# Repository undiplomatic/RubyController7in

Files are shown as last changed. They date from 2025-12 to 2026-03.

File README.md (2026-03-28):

# Open Source 7" FPV Controller with Display for RubyFPV

>[!NOTE]
>This is not a production ready controller, it may contain design faults. I am **not an engineer** and cannot vouch for its safety.
>Ergonomics are still very basic. Uses a low cost screen, with plans to update for a high brightness outdoor screen once testing completes. HDMI would also be useful for use with goggles, but not yet sure how to implement that.

>[!TIP]
>Although designed for RubyFPV, no reason it cant be used for other systems such as OpenHD so long as they support a Raspberry Pi. OpenIPC doesn't support control link at this time.

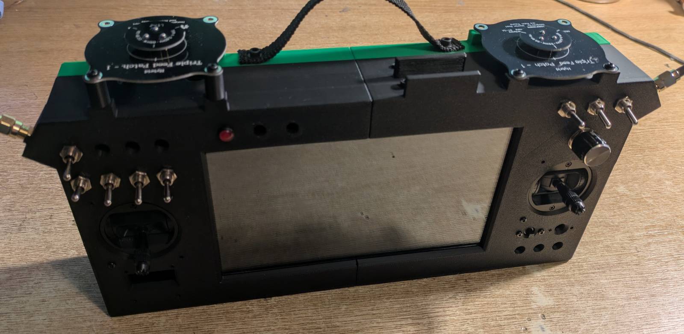
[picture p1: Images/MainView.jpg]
Main View


## Why RubyFPV
Around 2025 RubyFPV matured into a stable digital FPV and link system. Users report it operates flawlessly without stutters or break-ups. In my home testing, Ruby achieves approximately 75% of the range of DJI O4. As of early 2026, RubyFPV is working on integrating specialist FPV modules which will further improve the link. These upcoming modules will provide an even more stable link, more range, and lower latency. They will support multiple frequency bands, a first for digital FPV, including traditional 5.8GHz and low-frequency bands for long range.

Open source FPV eliminates vendor lock-in, privacy concerns, and lack of feedback associated with closed systems. For example, DJI has been shown to have back doors in their hardware, forcing changes without an update in the UK. DJI also require activation, restrict certain features for non-DJI drones (eg head tracking), and leave certain features out of date (eg SBUS). Because RubyFPV is open, it can be fully customised for industrial, academic, or developer applications. It also handles video, telemetry, and control signals over a single link and supports advanced features like signal relaying and antenna trackers.

## Why This Controller
This 3D-printed controller includes features missing on commercial systems, such as a six-position switch specifically for Ardupilot flight modes, along with a high number of assignable switches. Because RubyFPV supports multiple concurrent links across different frequencies, this controller has the internal space to house multiple transceiver modules simultaneously.

## Features
| Feature | Description | |
| :--- | :--- | :--- |
| 7 inch screen | Good size screen, reasonably priced | ✅ |
| Combined Screen and Controller | No need for a separate control link such as ELRS | ✅ |
| Raspberry Pi / Radxa Rock based |  | ✅ |
| Open source joystick controller | Uses highly configurable FreeJoy HID controller, allowing large number of switches and pots | ✅ |
| Radiomaster AG1 Hall Sensor Gimbals | Beware: the hall sensor wires on Radiomaster are mis-coloured, remove wires and check polarity printed on sensors. Available in CNC or low cost plastic. | ✅ |
| Built in open source patch antennas | Low profile, low cost, perfect radiation beam for long range | ✅ |
| Diversity omni antennas | V shaped antennas to reduce blind spots | ✅ |
| RTL EU2 Wifi chips with heat sinks | Transceivers mount on integrated heat sinks | ✅ |
| Active cooling | Two large fans | ✅ |
| Rotary switch | Rotary switches support large number of positions, suitable for flight modes on Ardupilot etc | ✅ |
| Power switch guard | Knock guard protects against accidental on/off | ✅ |
| Mini nav stick | Used to navigate through RubyFPV menus. Spare nav stick for screen control. | ✅ |
| LCD Screen | Used for aux display on RubyFPV | ✅ |
| External USB port | Used to update firmware | ✅ |
| High brightness outdoor screen | 2000 nit screen coming later | ⏳ |
| Ergonomics | Improved ergonomics coming later | ⏳ |

>[!NOTE]
>Files created in FreeCAD for easy updating.
>STL files in multiple parts to fit typical 3D printers.

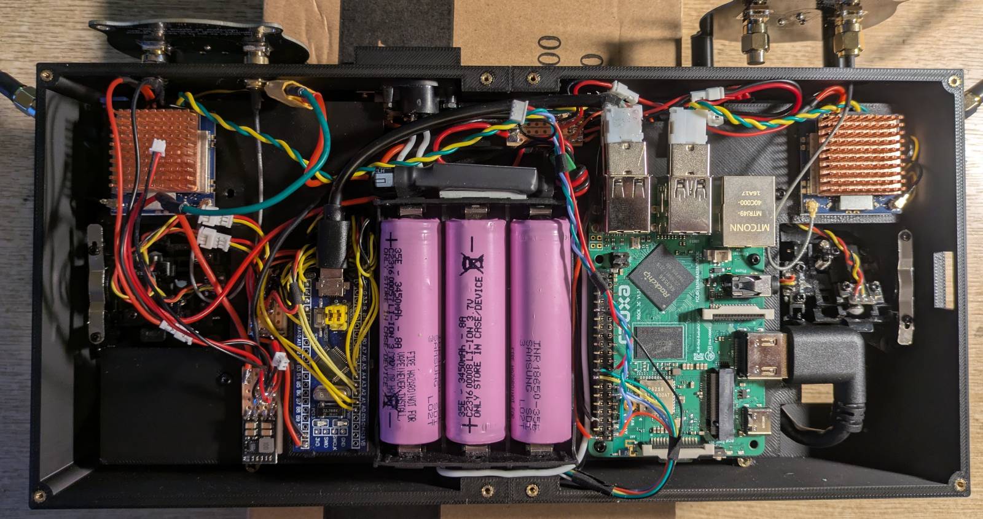
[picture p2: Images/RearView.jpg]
Rear View

Wiring looks complex: it's not, the switches and gimbal wiring create that illusion.

>[!NOTE]
>The RTL chips get hot. Heat sinks are glued into the board, and the RTL modules are attached to the sinks using thermal adhesive tape.
>The board you see creates two levels inside the controller. The bottom level houses the screen, wiring and gimbals. The top level houses the Radxa/Raspberry, batteries, HID joystick controller, and RTL modules.

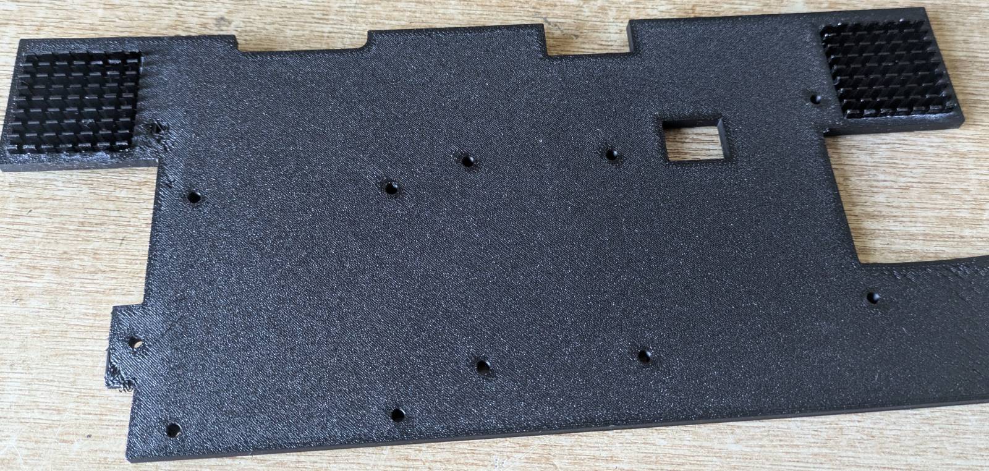
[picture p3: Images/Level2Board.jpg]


## Radiomaster AG01 Gimbal Wiring Warning

I found that the gimbals do not follow red/black wiring convention, with the red wire connected to the -ve and black wire to the +ve. The hall sensors have + and - markings on the PCB which appear correct.

## Part List

| | Part | Description |
| :--- | :--- | :--- |
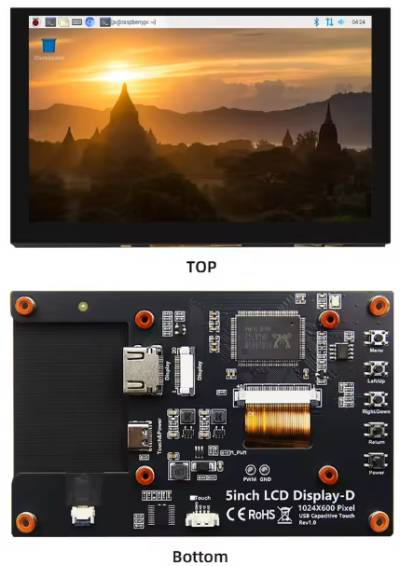
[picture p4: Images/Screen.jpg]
|  | Screen | Generic Raspberry Pi HDMI display, 7 inch. Find this **exact** screen to ensure a fit. |
| | SoC Computer | Raspberry Pi or Radxa Rock |
| | Gimbals | Radiomaster AG01 gimbals |
| | RTL WiFi modules | Two RTL8812EU-CG Long Distance drone modules act as transceivers |
| | Blue Pill STM32 | Low cost device that is flashed with FreeJoy. Solder all the hall sensors, switches, and pots to it. |
| | BEC or Voltage Regulators | 5.0v. Beware, many are 5.2v which isn't ideal, though still in tolerance for some 5v devices. But check voltage is no higher! I run TWO regulators, one powers the SoC and one RTL WiFi module. The other powers the fans and second RTL module. This is recommended so that a short in the fans doesn't cause outage. |
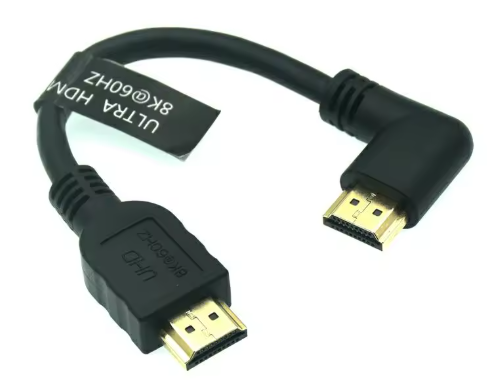
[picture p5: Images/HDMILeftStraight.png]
HMDI Cable Left-Straight 15cm
|  | HDMI Cable | 15cm left plug and straight plug other end |
| | Battery holder | Three 18650 cell holder |
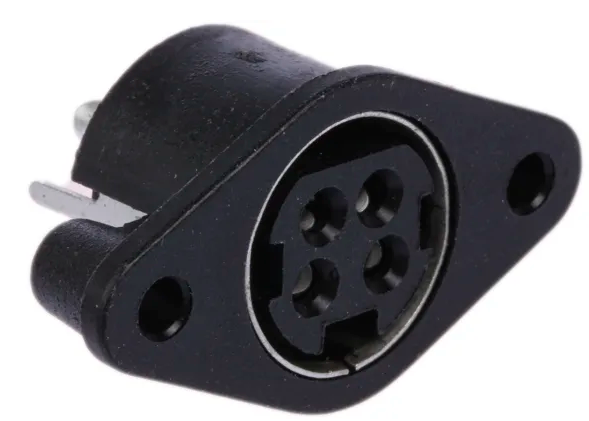
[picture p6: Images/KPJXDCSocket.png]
Kycon socket
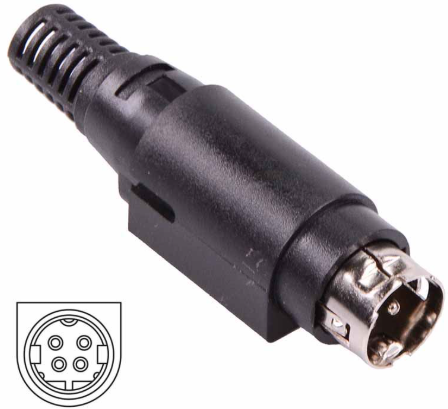
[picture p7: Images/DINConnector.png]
DIN Connector
|  | DC Socket | Kycon KPJX Straight DC Socket, part KPJX-PM-4S. These are not cheap, but are the only 4 pin DC plugs I can find. Male end is more common, often called a DIN plug even though not DIN compatible. Real DIN plugs have thinner pins and not suitable for DC charging. |
| | Patch Antennas x2 | Triple feed patch antenna, low cost, open source design. You also need 50 ohm SMA terminals for them to work properly. |
| | Omni Antennas x2 | SMA Antennas |
| | Fans x2 | 4010 5v fans. Wire to second voltage regulator for safety. |
| | Slide Switch | 6amp switch for main power, 27.5mm hole spacing +/- 1mm. Typically marked "6a 125v/3a 240v". Product title often states 3 amps, but specs show 6 amp at lower voltages. |
| | Toggle switches | MTS series generic toggle switches |
| | Rotary switch | SR16 |
| | Heat sinks | 30x30mm alu |
| | SMA U.FL Connectors | Two male SMAs for the omni antennas and two females for the patch antennas. The other end should be IPEX or U.FL. I believe they are the same, one being a brand name. |
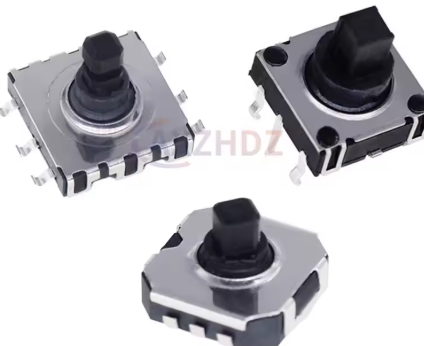
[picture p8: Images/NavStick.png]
Mini Nav Switch
| | Mini Nav switch | Five Way Switch SMD DIP 6Pin Multi Directional Mobile Navigation Switch Touch Reset Key 7.5x7.5 |
| | LCD Display | Optional 0.96" I2C OLED Display Module |
| | LEDs | 6mm hole, 5v. I suggest using 12/24v LED for the power LED to keep brightness low. |
| | M2 brass inserts | |
| | Current/voltage sensor | INA219 I2C sensor. I found only the Ada Fruit was detected by my Radxa. Raspberry Pi should work with generic sensors. |
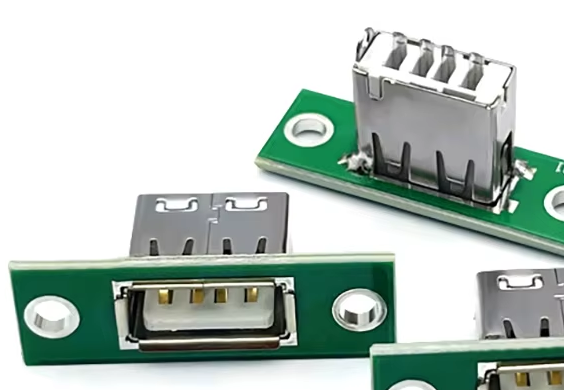
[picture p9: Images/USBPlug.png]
USB Plug
|  | USB plugs | Self solder type, male and one female |
| | Silicone wire | 30 AWG |
| | 1.25mm Connectors | Small, JST like connectors such as Molex PicoBlade or MX 1.25 |
| | 18650 Li-Ion Cells | |
| | 2mm Steel Wire | Used as dowels to join the two halves of the controller case |

... and other misc items: thermal adhesive tape, resistors for rotary switch and three position switches, and probably more things I've forgotten about.

## Charging Lead

The controller uses a 4-pin DC plug as a balance lead, with pins wired to each junction of the three battery cells. Due to space constraints, there is no dedicated main power socket. Since most chargers do not support charging  via the balance lead alone, you can use a breakout lead (an XT30 plug connected to the two outer junctions). While this is electrically the same as a standard charging setup, the power is "tapped" from  balance wires, therefore, you must charge at a low current to prevent issues.

```
DC PLUG PIN:(1)         (2)         (3)         (4)
             |           |           |           |
             +--[Cell1]--+--[Cell2]--+--[Cell3]--+
             |  (3.7V)      (7.4V)      (11.1V)  |
             |                                   |
 XT30:  NEG (-)                             POS (+)
```

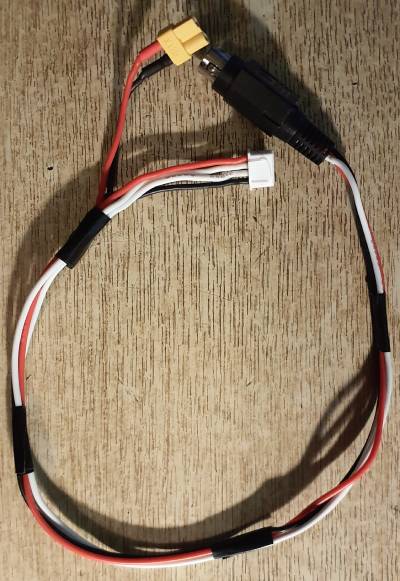
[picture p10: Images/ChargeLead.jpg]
Charge Lead


## USB and hall sensor wiring

* __Tightly__ twist the USB data wires and keep them as short as possible
* __Lightly__ twist the hall sensor wires and keep them as short as possible
* WiFi transceivers should take power direct from the voltage regulators. USB power is insufficient at high outputs.

## Three position switches

* These should be wired to an analogue terminal on the Joystick Blue Pill STM32 controller.
* Two 5k resistors from centre terminal to outer terminals.
* Power and Ground from the joystick controller to the switch outer terminals.
* Centre switch terminal to analogue pin

```
SWITCH PIN: (GND)   (Analogue Pin)    (3.3v)
                |          |          | 
                +---[R1]---+---[R1]---+
                [#### SWITCH BODY ####]

```

## Rotary switch

* Solder small resistors between the terminals create a "voltage ladder" (Google "rotary switch voltage ladder").
* The total resistance should sum to ~10 kOhms
* Wire to an analogue input on the Joystick HID Blue Pill STM32 controller

Ardupilot flight mode channel is a pain as the switch boundaries are not configurable, so each notch on the switch may not move the flightmode by one setting. This is because Ardu doesn't use the first and last 10% of the band. Thankfully, FreeJoy *axes curves* can fix this. The image shows how to configure the curve for a six position switch: notice that the line starts at -80% and ends at 80%, which compresses the band into what Ardu expects.

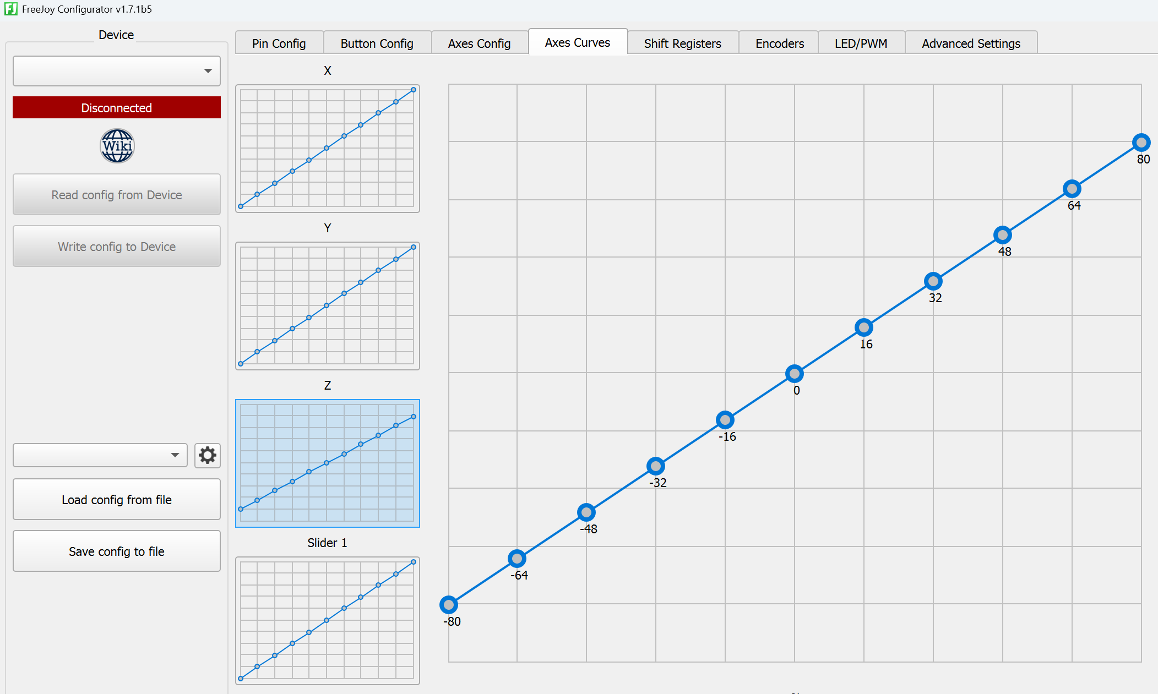
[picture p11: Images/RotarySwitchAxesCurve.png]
Axes curve to fix switch boundaries in Ardupilot


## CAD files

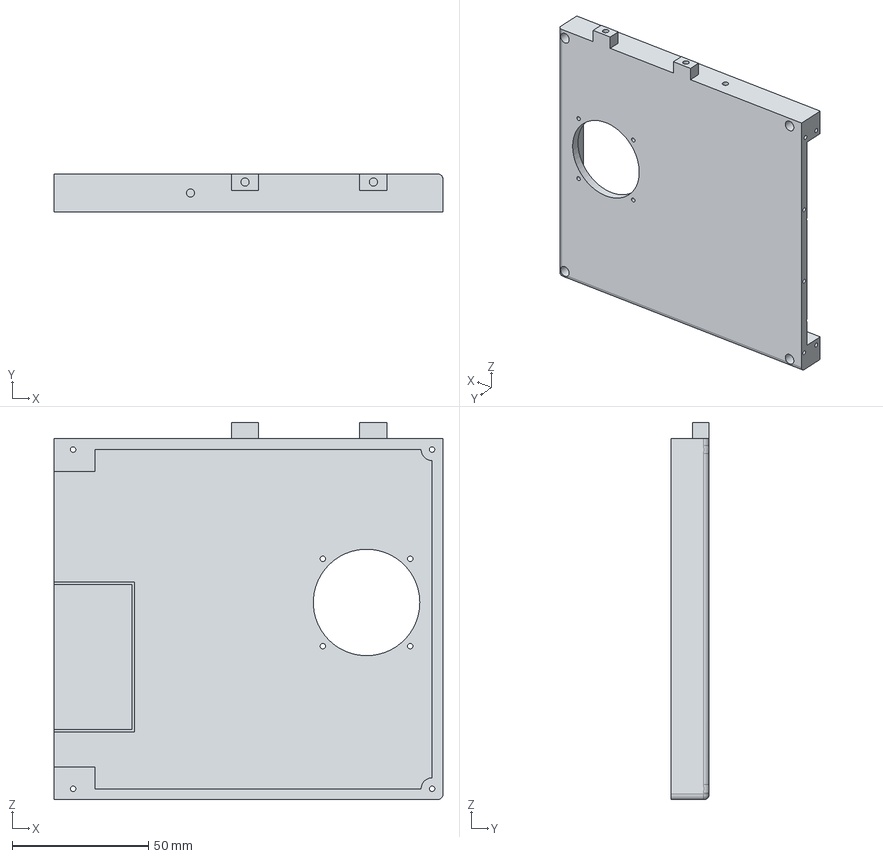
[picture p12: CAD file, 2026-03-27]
Case-RearRight.step
142.5 x 14.0 x 138.2 mm

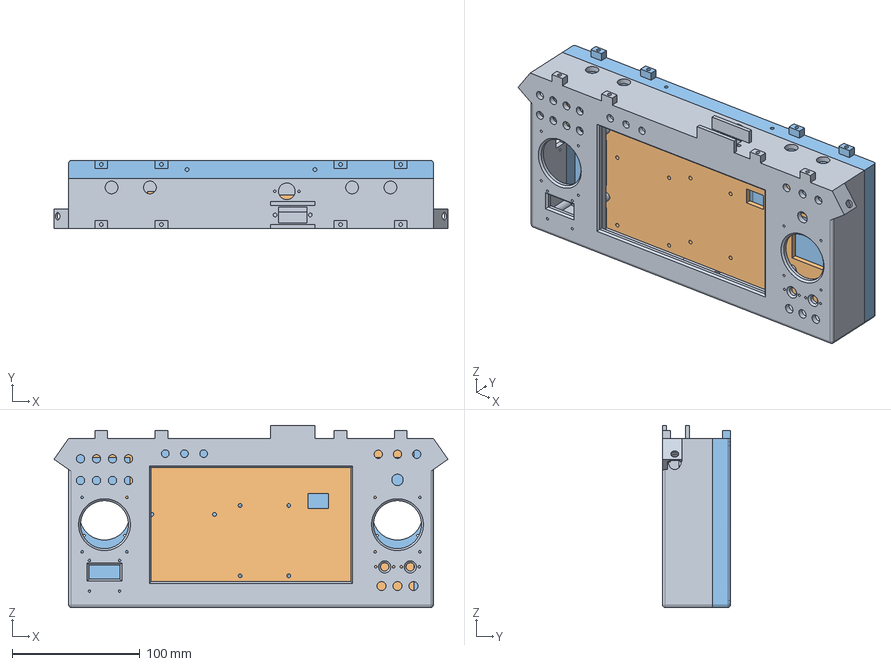
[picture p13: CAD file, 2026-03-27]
Case.FCStd
307.9 x 53.0 x 142.2 mm
Front
Level2
RearCover

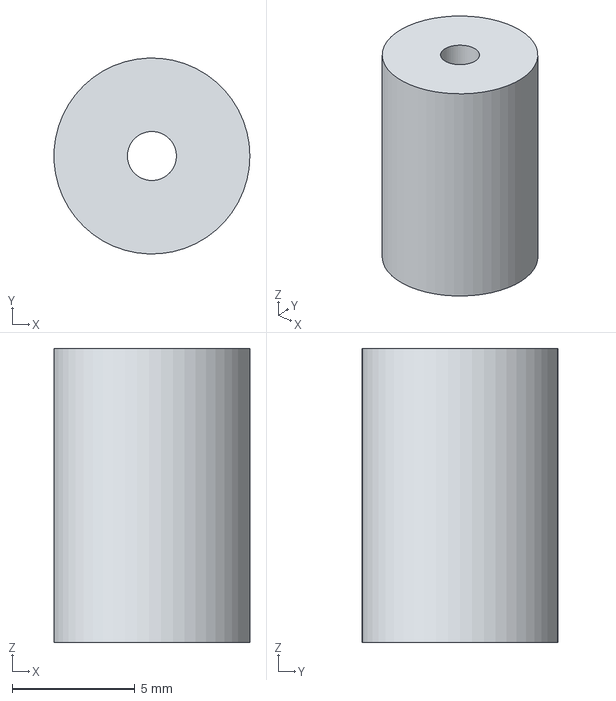
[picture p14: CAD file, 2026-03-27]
PatchAntennaSpacer.step
7.99 x 8.00 x 12.0 mm

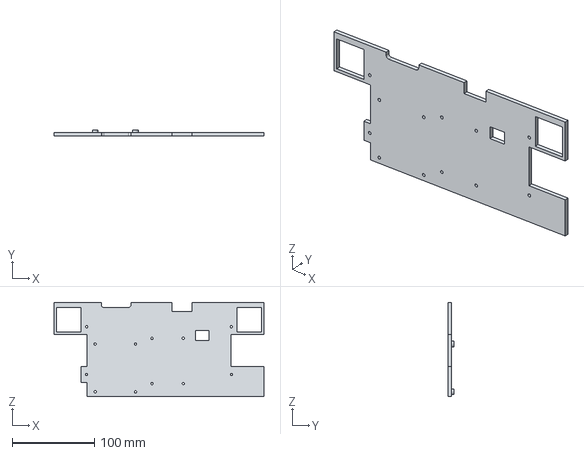
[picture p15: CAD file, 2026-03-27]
Case-Level2.step
255.0 x 7.00 x 114.2 mm

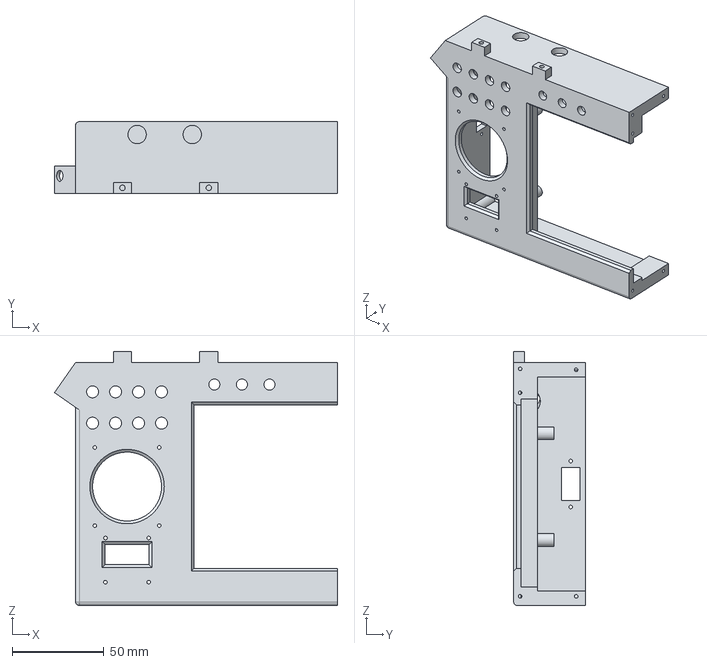
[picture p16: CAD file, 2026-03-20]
Case-LeftPart.step
154.0 x 39.0 x 138.2 mm

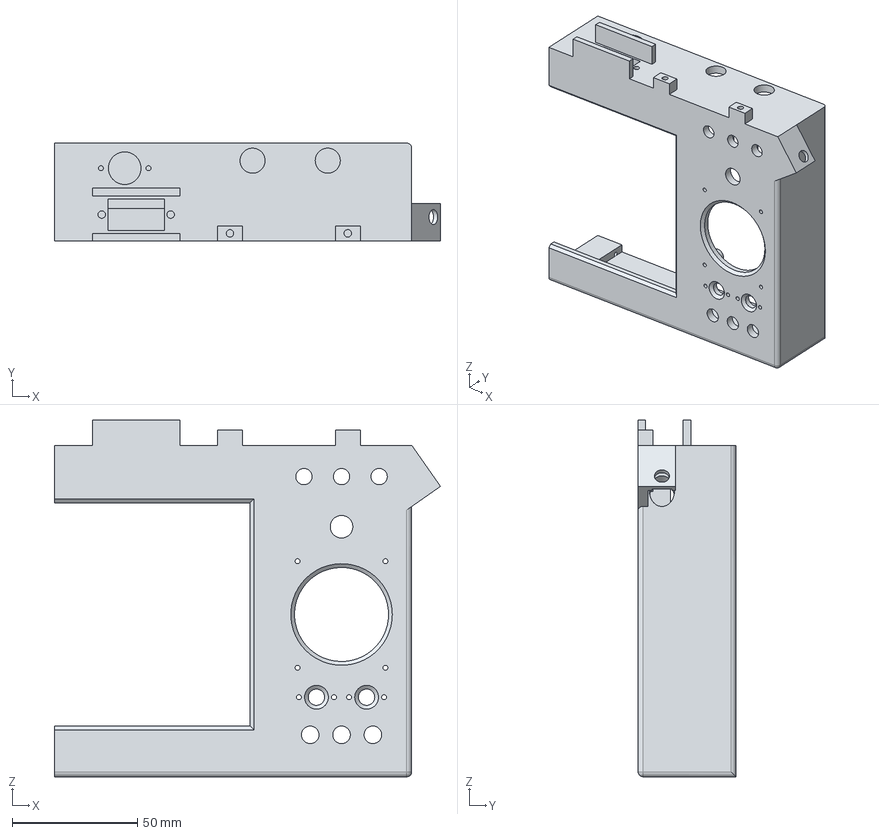
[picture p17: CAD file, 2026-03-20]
Case-RightPart.step
154.0 x 39.0 x 142.2 mm

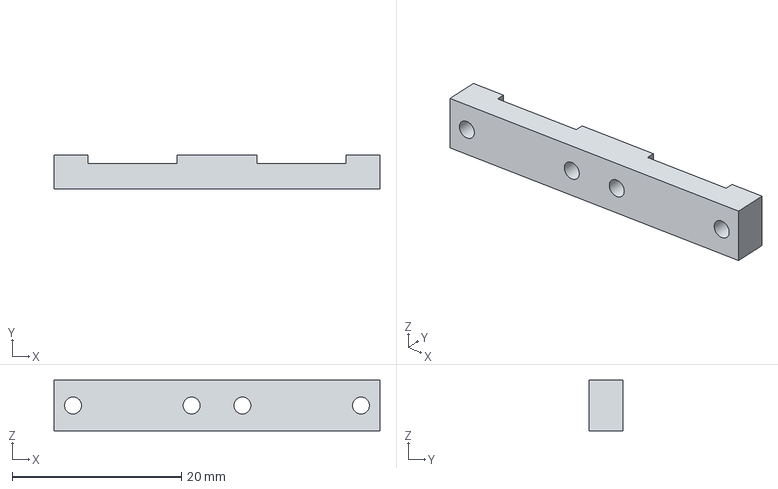
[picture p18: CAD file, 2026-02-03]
NavButtonRetainer.step
38.5 x 4.00 x 6.00 mm

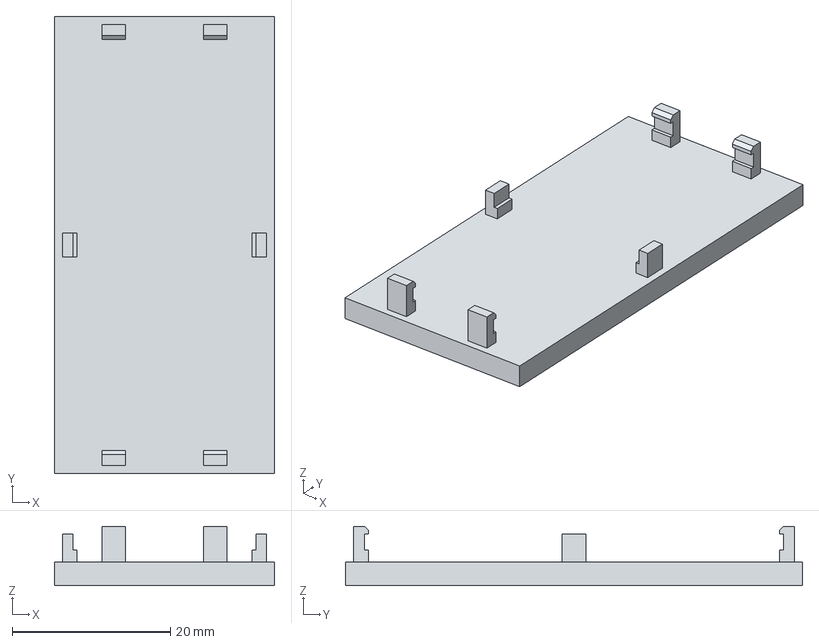
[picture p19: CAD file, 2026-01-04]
STM32BluePillMount.step
27.8 x 57.7 x 7.50 mm

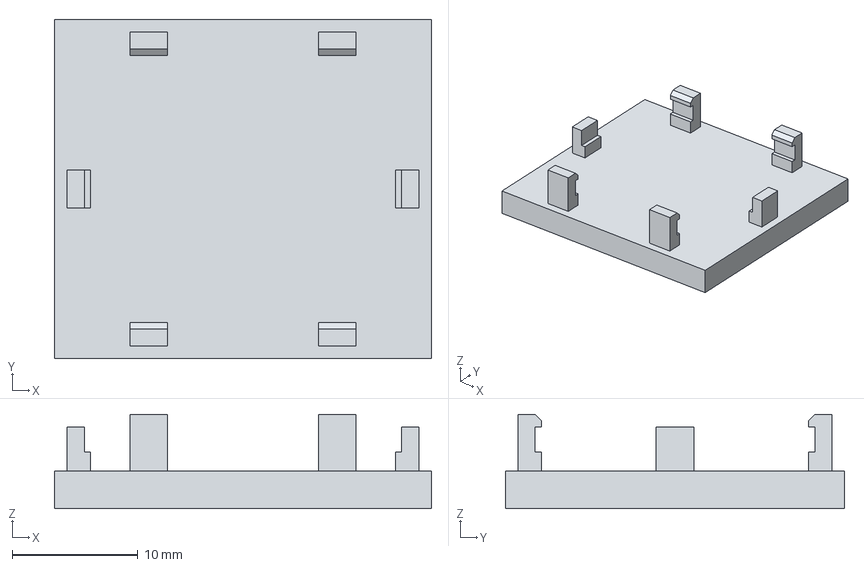
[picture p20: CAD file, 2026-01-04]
INA219Mount.step
30.0 x 27.0 x 7.50 mm

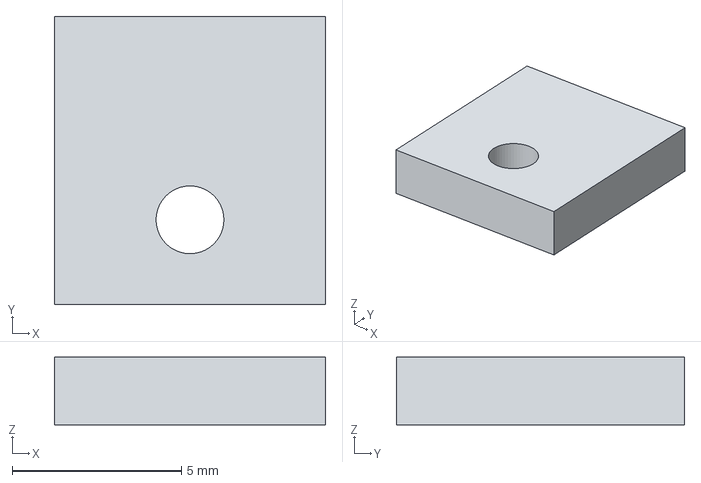
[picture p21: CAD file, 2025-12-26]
DisplayRetainer.step
8.00 x 8.50 x 2.00 mm

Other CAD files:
Case-RearLeft.step
DisplayRetainer.FCStd
INA219Mount.FCStd
NavButtonRetainer.FCStd
PatchAntennaSpacer.FCStd
STM32BluePillMount.FCStd

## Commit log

2025-12-21 Created master sketch
    [Front.FCStd]
2025-12-21 Master sketch wall
    [Front.FCStd]
2025-12-21 Start switch hole sketch
    [Front.FCStd]
2025-12-21 Switch holes expanded
    [Front.FCStd]
2025-12-21 Front face sketch
    [Front.FCStd]
2025-12-21 Front face wall
    [Front.FCStd]
2025-12-21 Added main power switch hole
    [Front.FCStd]
2025-12-21 Added front face chamfer
    [Front.FCStd]
2025-12-21 Display support
    [Front.FCStd]
2025-12-21 Inserts for display support
    [Front.FCStd]
2025-12-21 Display port clearance
    [Front.FCStd]
2025-12-21 Front face brass insert
    [Front.FCStd]
2025-12-21 Chamfer tweak
    [Front.FCStd]
2025-12-21 Joint blocks
    [Front-Body.step, Front.FCStd]
2025-12-21 Dowel holes
    [Front.FCStd]
2025-12-22 Front-rear face connect blocks
    [Front.FCStd]
2025-12-22 Front-rear face inserts
    [Front.FCStd]
2025-12-22 Front-rear face double insert
    [Front.FCStd]
2025-12-23 Fixed screen support size
    [Front-Body.step, Front-LeftPart.step, Front-RightPart.step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]
2025-12-25 Fit for Zorro gimbals
    [Front-LeftPart.3mf, Front-LeftPart.step, Front-RightPart.step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]
2025-12-25 Create 3mf
    [Front.3mf]
2025-12-26 Switch hole adjustment
    [Front-LeftPart.step, Front-RightPart.step, Front.3mf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]
2025-12-26 Aux switch rearrangement
    [Front.FCStd]
2025-12-26 Regenerate print files
    [Front-LeftPart.step, Front-RightPart.step, Front.3mf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]
2025-12-26 Create display retainer
    [DisplayRetainer.FCStd]
2025-12-26 Create step files
    [DisplayRetainer.step, NavButtonRetainer.step]
2025-12-26 Missing retainer hole
    [Front.3mf, NavButtonRetainer.FCStd, NavButtonRetainer.step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]
2025-12-26 Aux Switch support
    [Front.FCStd]
2025-12-27 Level2 mount
    [Front.FCStd]
2025-12-27 Adjust level 2 height
    [Front.FCStd]
2025-12-27 Fix multipart pocket
    [Front.FCStd]
2025-12-27 Update step
    [Front-LeftPart.step, Front-RightPart.step, Front.3mf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]
2025-12-27 Layer 2 corer
    [Front.FCStd]
2025-12-27 Update Level2 post measurement
    [Front.FCStd]
2025-12-27 Adjust Level 2 height 20to16mm
    [Front.FCStd]
2025-12-27 Adjust Level 2 wing
    [Front.FCStd]
2025-12-27 Level 2 bottom wings
    [Front.FCStd]
2025-12-27 Added grips
    [Front.FCStd]
2025-12-28 Adjust grip fillet
    [Front-LeftPart.step, Front-RightPart.step, Front.FCStd]
2025-12-29 Fixed Level 2 DOFs. Removed Level 2 main board pocket.
    [Front.FCStd]
2025-12-29 Creat new 3mf
    [Front.3mf]
2025-12-31 Tweak SoC location
    [Front-Level2.step, Front.FCStd]
2025-12-31 Trim level 2 for HDMI
    [Front.FCStd]
2026-01-01 RTL mount
    [RTL8812EUMount.FCStd, RTL8812EUMount.step]
2026-01-04 Updated master sketch
    [RTL8812EUMount.FCStd, RTL8812EUMount.step]
2026-01-04 Create gimbal hall sensor bracket
    [Gimbal Hall Sensor Mount.FCStd, Gimbal Hall Sensor Mount.dxf]
2026-01-04 Decoupled base
    [RTL8812EUMount.FCStd]
2026-01-04 Posts positioning improved
    [RTL8812EUMount.FCStd, RTL8812EUMount.step]
2026-01-04 STM32BluePill Created
    [STM32 BluePill Mount.FCStd]
2026-01-04 Remove filename spaces
    [Front.FCStd, GimbalHallSensorMount.FCStd, GimbalHallSensorMount.dxf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]
2026-01-04 Post positioning fix
    [STM32BluePillMount.FCStd]
2026-01-04 Generate STM32 Step
    [STM32BluePillMount.step]
2026-01-04 Create mount
    [INA219Mount.FCStd, INA219Mount.step, MatekMicroBECMount.FCStd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]
2026-01-04 Update post config
    [RTL8812EUMount.FCStd, RTL8812EUMount.step, STM32BluePillMount.FCStd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]
2026-01-07 Insert holes temp changed to 2mm
    [Front-LeftPart.step, Front-Level2.step, Front-RightPart.step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]
2026-01-07 Temp change insert hole to 2mm
    [Front.FCStd]
2026-01-22 Battery holder mount
    [Front.FCStd]
2026-01-23 Taller walls
    [Front.FCStd]
2026-01-25 Added power port
    [Front.FCStd]
2026-01-28 Level 2 notch
    [Front.FCStd]
2026-01-28 Removed mid wall supports
    [Front.FCStd]
2026-01-28 Moved pillars
    [Front.FCStd]
2026-01-28 Adjust nav hole size
    [Front.FCStd]
2026-02-03 Move power plug, tweak switch location
    [Front.FCStd]
2026-02-08 Raised level 2
    [Front.FCStd]
2026-02-08 Level 2 clearance
    [Front.FCStd]
2026-02-08 LED power
    [Front.FCStd]
2026-02-08 Rear cover blank
    [Front.FCStd]
2026-02-09 Rear cover battery mark
    [Case.FCStd]
2026-02-09 Rear cover multipart
    [Case.FCStd]
2026-03-06 Bigger fan
    [Case.FCStd]
2026-03-19 Antenna mount
    [2026-02-07 2220 First setup.cfg, 2026-03-04 2031 Flight mode axis curve.cfg, Case-RearLeft.3mf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]
2026-03-19 Antenna mount mirror
    [Case.FCStd]
2026-03-19 Remove antenna ports
    [Case.FCStd]
2026-03-19 Patch mounts
    [Case.FCStd]
2026-03-19 Back cover depth adjust
    [Case.FCStd]
2026-03-19 Patch posts rear
    [Case.FCStd]
2026-03-20 Adjust patch post length
    [Case.FCStd]
2026-03-20 Patch fittings
    [Case.FCStd]
2026-03-20 Power switch port
    [Case.FCStd]
2026-03-20 Power guard
    [Case.FCStd]
2026-03-20 USB port
    [Case.FCStd]
2026-03-20 Antenna retention slot
    [Case.FCStd]
2026-03-20 Ergonomic fillet
    [Case.FCStd]
2026-03-26 Level 2 heat sink
    [Case.FCStd]
2026-03-26 HID cable hole
    [Case-Level2.step, Case.FCStd]
2026-03-27 Rear cover screw clearance
    [Case-RearLeft.3mf, Case-RearLeft.step, Case-RearRight.step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]
2026-03-27 Charge lead
2026-03-27 Charge balance lead
2026-03-27 Charge lead wiring diagram
2026-03-27 Wiring tip
2026-03-27 3 pos switch
2026-03-27 Rotary switch
2026-03-27 Axes curve image insert
2026-03-28 Slide switch tweak
2026-03-28 Radiomaster gimbal wiring warning
